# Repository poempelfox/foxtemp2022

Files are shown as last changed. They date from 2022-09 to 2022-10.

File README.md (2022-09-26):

# FoxTemp 2022

## Intro

This repository contains info about, firmware and a case for the
FoxTemp-Device version 2022.

This is very close to its predecessor, the "FoxTemp 2016",
the main changes are:
- uses a SHT41 (or SHT45) as a sensor instead of a SHT31/35. The
  SHT41 boasts with improved accuracy over its predecessor:
  a typical accuracy of &plusmn;1.8% RH (SHT31: &plusmn;2%)
  and &plusmn;0.2&deg;C (SHT31: &plusmn;0.3&deg;C) in the
  relevant ranges.
- uses a "Canique MK2" as the microprocessor base board, which
  in itself is a "Moteino V4" clone, so you could use that one as
  well. Unfortunately, there is no variant with a boost-converter
  onboard, like there was with the "JeeNode Micro". The boost
  converter needs to be an external "Canique Boost".

One thing did not change: The over-the-air protocol. It is not
possible to distinguish a foxtemp2022 from a foxtemp2016 at the
receiving end, both transmit exactly the same data format.

Note that you will also need a way to receive the wirelessly transmitted
data. I simply used a JeeLink v3c,
which is a simple USB transceiver for 868 MHz that is commonly used in
non-commercial home-automation systems. As such it is well supported by
FHEM, a popular non-commercial and cloud-free home-automation software.
A FHEM module for using it to feedg temperature data from foxtemp2016
or foxtemp2022 devices into FHEM can be found in the foxtemp2016 repository.

## Hardware

### Intro

This has been designed for low power usage, and when not transmitting the circuitry
uses only a fraction of a miliampere (around 0.05 mA at 2.8 volts input voltage,
this depends on the input voltage obviously). This should guarantee a long
battery life, but it's still unknown how long exactly this will be.
It also could be better if we weren't needlessly using a 16 MHz crystal
oscillator.
It will probably be slightly shorter than the one foxtemp2016 achieved,
but in the same order of magnitude.

### BOM

The hardware uses as many "ready made" parts as possible and just slaps them
together. The bill of materials therefore is short:

* [Canique MK2](https://www.canique.de/mk2), which is a "Moteino"
  clone and an ATtiny328P based microcontroller module with an
  RFM69HW 868 MHz wireless module. There are multiple versions of
  that, the one used here is the one without onboard voltage
  converter or flash.
* [Canique Boost](https://www.canique.de/boost), a very efficient
  step-up/boost converter. I can be powered by anything from 0.8
  to 3.3 volts and will generate the 3.3 volts the microcontroller
  and peripherals use from that.
* SHT41 temperature sensor, in the form of a
  [random SHT41 breakout board](https://www.soselectronic.com/products/various/sht-41-bob-373380).
  This is used because the SHT41 is very tiny, so soldering it directly
  without damaging it would not be an easy task, and because the breakout
  board serves perfectly as what would be called a "shield" in the Arduino
  world: It's plugged/stacked on top of the microcontroller board.
* Goobay 78467 battery tray. This is simply a battery holder for two
  AA / mignon batteries that has cables attached.
* 6pin angled or non-angled pin strip for the FTDI connector of the Canique MK2.
* 4pin (non-angled) pin strips male and female for connecting and mounting the
  SHT41 on top of the Canique MK2.
* 2pin (non-angled) pin strips male and female for connecting and mounting the
  Canique Boost on top of the Canique MK2

### Putting it together

Wanting to keep things as simple and compact as possible, I soldered the few
parts directly together as a stack. In the following description,
"top" means the side of the Canique MK2 / Moteino with the microcontroller,
the radio module is at the "bottom".

(to be continued)

## Case

A reference design for a laser-cut case that will fit the sensor construction
and the batteries (just like for foxtemp2016) is in the works. It is not
finished yet.

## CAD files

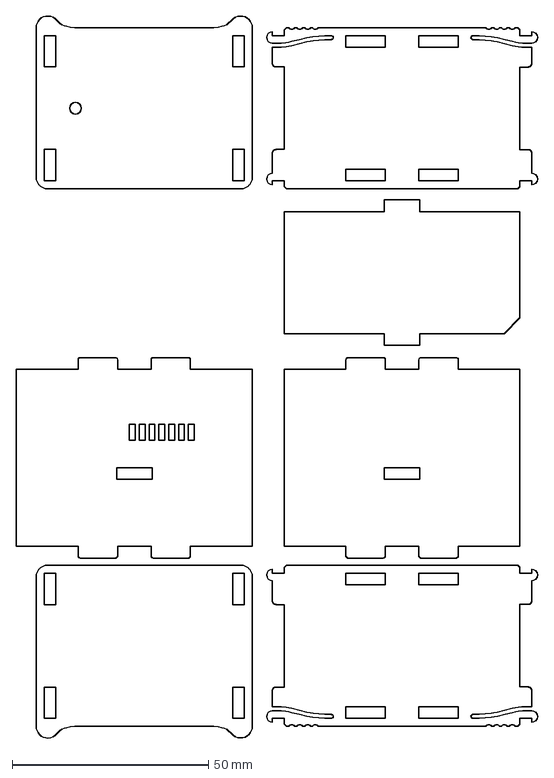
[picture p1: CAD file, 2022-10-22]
case/foxtempcaseacryl.dxf
132.6 x 183.7 mm

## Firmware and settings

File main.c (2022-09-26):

/* $Id: main.c $
 * main for JeeNode Weather Station, tieing all parts together.
 * (C) Michael "Fox" Meier 2016
 */

#include <avr/io.h>
#include <avr/interrupt.h>
#include <avr/wdt.h>
#include <avr/eeprom.h>
#include <avr/power.h>
#include <avr/sleep.h>
#include <stdio.h>
#include <string.h>
#include <util/delay.h>

#include "adc.h"
#include "eeprom.h"
#include "rfm69.h"
#include "sht4x.h"

/* We need to disable the watchdog very early, because it stays active
 * after a reset with a timeout of only 15 ms. */
void dwdtonreset(void) __attribute__((naked)) __attribute__((section(".init3")));
void dwdtonreset(void) {
  MCUSR = 0;
  wdt_disable();
}

/* The values last measured */
/* temperature. 0xffff on error, 14 useful bits. */
uint16_t temp = 0;
/* humidity. 0xffff on error, 14 useful bits */
uint16_t hum = 0;
/* Battery level. Range 0-255, 255 = our supply voltage = 3,3V */
uint8_t batvolt = 0;
/* How often did we send a packet? */
uint32_t pktssent = 0;

/* This is just a fallback value, in case we cannot read this from EEPROM
 * on Boot */
uint8_t sensorid = 3; // 0 - 255 / 0xff

/* The frame we're preparing to send. */
static uint8_t frametosend[10];

static uint8_t calculatecrc(uint8_t * data, uint8_t len)
{
  uint8_t i, j;
  uint8_t res = 0;
  for (j = 0; j < len; j++) {
    uint8_t val = data[j];
    for (i = 0; i < 8; i++) {
      uint8_t tmp = (uint8_t)((res ^ val) & 0x80);
      res <<= 1;
      if (0 != tmp) {
        res ^= 0x31;
      }
      val <<= 1;
    }
  }
  return res;
}

/* Fill the frame to send with out collected data and a CRC.
 * The protocol we use is that of a "CustomSensor" from the
 * FHEM LaCrosseItPlusReader sketch for the Jeelink.
 * So you'll just have to enable the support for CustomSensor in that sketch
 * and flash it onto a JeeNode and voila, you have your receiver.
 *
 * Byte  0: Startbyte (=0xCC)
 * Byte  1: Sensor-ID (0 - 255/0xff)
 * Byte  2: Number of data bytes that follow (6)
 * Byte  3: Sensortype (=0xf7 for FoxTemp)
 * Byte  4: temperature MSB (raw value from SHT31)
 * Byte  5: temperature LSB
 * Byte  6: humidity MSB (raw value from SHT31)
 * Byte  7: humidity LSB
 * Byte  8: Battery voltage
 * Byte  9: CRC
 */
void prepareframe(void)
{
  frametosend[ 0] = 0xCC;
  frametosend[ 1] = sensorid;
  frametosend[ 2] = 6; /* 6 bytes of data follow (CRC not counted) */
  frametosend[ 3] = 0xf7; /* Sensor type: FoxTemp */
  frametosend[ 4] = (temp >> 8) & 0xff;
  frametosend[ 5] = (temp >> 0) & 0xff;
  frametosend[ 6] = (hum >> 8) & 0xff;
  frametosend[ 7] = (hum >> 0) & 0xff;
  frametosend[ 8] = batvolt;
  frametosend[ 9] = calculatecrc(frametosend, 9);
}

void loadsettingsfromeeprom(void)
{
  uint8_t e1 = eeprom_read_byte(&ee_sensorid);
  uint8_t e2 = eeprom_read_byte(&ee_invsensorid);
  if ((e1 ^ 0xff) == e2) { /* OK, the 'checksum' matches. Use this as our ID */
    sensorid = e1;
  }
}

/* This is just to wake us up from sleep, it doesn't really do anything. */
ISR(WDT_vect)
{
  /* Nothing to do here. */
}

int main(void)
{
  /* Initialize stuff */
  /* Clock down from 16.0 to 0.25 MHz. */
  CLKPR = _BV(CLKPCE);
  CLKPR = _BV(CLKPS2) | _BV(CLKPS1);
  
  _delay_ms(1000); /* Wait. */

  rfm69_initport();
  adc_init();
  sht4x_init();
  loadsettingsfromeeprom();
  
  _delay_ms(1000); /* The RFM12 needs some time to start up */
  
  rfm69_initchip();
  rfm69_setsleep(1);
  
  /* Enable watchdog timer interrupt with a timeout of 8 seconds */
  WDTCSR = _BV(WDCE) | _BV(WDE);
  WDTCSR = _BV(WDE) | _BV(WDIE) | _BV(WDP0) | _BV(WDP3);

  /* Prepare sleep mode */
  set_sleep_mode(SLEEP_MODE_PWR_DOWN);
  sleep_enable();

  /* Disable unused chip parts and ports */
  /* We do not use any of the timers */
  PRR |= _BV(PRTIM0) | _BV(PRTIM1) | _BV(PRTIM2);
  /* we don't use hardware TWI */
  PRR |= _BV(PRTWI);
  /* Disable analog comparator */
  ACSR |= _BV(ACD);
  /* Disable unneeded digital input registers for all unused ADC pins
   * (they can cause significant power drain in some conditions).
   * Do not disable them for AIN0/1 aka PD6/7, they are in use! */
  DIDR0 |= _BV(ADC5D) | _BV(ADC4D) | _BV(ADC3D) | _BV(ADC2D) | _BV(ADC1D) | _BV(ADC0D);
  /* PD2 is the IRQ line from the RFM69. We don't use it. Make sure that pin
   * is tristated on our side (it won't float, the RFM69 pulls it) */
  PORTD &= (uint8_t)~_BV(PD2);
  DDRD &= (uint8_t)~_BV(PD2);

  /* there is a LED connected to PB1 */
  PORTB &= (uint8_t)~_BV(PB1);
  DDRB |= _BV(PB1);
  /* All set up, enable interrupts and go. */
  sei();

  sht4x_startmeas();

  uint16_t transmitinterval = 2; /* this is in multiples of the watchdog timer timeout (8S)! */
  uint8_t mlcnt = 0;
  uint8_t readerrcnt = 0;
  while (1) { /* Main loop, we should never exit it. */
#ifdef BLINKLED
    PORTB |= _BV(PB1);
#endif /* BLINKLED */
    mlcnt++;
    if (mlcnt > transmitinterval) {
      rfm69_setsleep(0);  /* This mainly turns on the oscillator again */
      adc_power(1);
      adc_start();
      /* Fetch values from PREVIOUS measurement */
      struct sht4xdata hd;
      sht4x_read(&hd);
      temp = 0xffff;
      hum = 0xffff;
      if (hd.valid) {
        readerrcnt = 0;
        temp = hd.temp;
        hum = hd.hum;
      } else {
        readerrcnt++;
        if (readerrcnt > 5) {
          /* We could not read the SHT31 5 times in a row?! */
          /* Then force reset through watchdog timer. */
          while (1) {
            sleep_cpu();
          }
        }
      }
      sht4x_startmeas();
      /* read voltage from ADC */
      uint16_t adcval = adc_read();
      adc_power(0);
      /* we have the battery pack directly connected without a
       * voltage divider, while foxtemp2016 did have a voltage
       * divider, returning 10/11 of the real voltage. However,
       * it was also operating at 3.0V, while we run at 3.3V.
       * The factor between that is 11/10, which means that by
       * pure accident our reported voltage values are exactly
       * compatible with foxtemp2016 without any conversion. */
      batvolt = adcval >> 2;
      prepareframe();
      rfm69_sendarray(frametosend, 10);
      pktssent++;
      /* Semirandom delay: the lowest bits from the ADC are mostly noise, so
       * we use that */
      transmitinterval = 3 + (adcval & 0x0001);
      rfm69_setsleep(1);
      mlcnt = 0;
    }
#ifdef BLINKLED
    PORTB &= (uint8_t)~_BV(PB1);
#endif /* BLINKLED */
    wdt_reset();
    /* Disable Brown-Out-Detector during sleep to save power.
     * Timed sequence, both lines setting it are needed even though
     * they might seem redundant, and they must not be executed
     * more than 4 cycle before going to sleep. */
    sleep_bod_disable();
    sleep_cpu(); /* Go to sleep until the watchdog timer wakes us */
    /* We should only reach this if we were just woken by the watchdog timer.
     * We need to re-enable the watchdog-interrupt-flag, else the next watchdog
     * -reset will not just trigger the interrupt, but be a full reset. */
    WDTCSR = _BV(WDCE) | _BV(WDE);
    WDTCSR = _BV(WDE) | _BV(WDIE) | _BV(WDP0) | _BV(WDP3);
  }
}

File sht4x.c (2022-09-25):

/* $Id: sht4x.c $
 * Functions for reading the SHT 41 (or other SHT4x variants)
 * temperature / humidity sensor
 *
 * Also includes functions for bitbanging I2C over two pins of the AVR,
 * which mostly come from the old NTP LED clock project.
 */

#include <avr/io.h>
#include <inttypes.h>
#include <util/delay.h>
#include "sht4x.h"

/* The Port used for the connection */
#define BBTWIPORT PORTD
#define BBTWIPIN PIND
#define BBTWIDDR DDRD

/* Which pins of the port */
#define PWRPIN PD4
#define SDAPIN PD5
#define SCLPIN PD6
#define GNDPIN PD7

#define I2C_READ  0x01
#define I2C_WRITE 0x00

/* The I2C address of the sensor. */
#define SHT4X_I2C_ADDR (0x44 << 1)

/* Commands for the sensor.  Only the ones we are likely
 * to use are listed here, look up the rest in the data sheet. */
/* Measurement with high precision */
#define SHT4X_CMD_MEASURE_HIGH 0xFD

/* FIXME */
#define DELAYVAL 14

void sht4x_init(void)
{
  /* We abuse two I/O ports to provide Power to the SHT4x */
  BBTWIPORT &= (uint8_t)~_BV(GNDPIN);
  BBTWIDDR |= _BV(GNDPIN);
  BBTWIPORT |= _BV(PWRPIN);
  BBTWIDDR |= _BV(PWRPIN);
  /* Initialize I2C bus: Enable pullups. */
  BBTWIPORT |= _BV(SCLPIN);
  BBTWIPORT |= _BV(SDAPIN);
  /* There is nothing to initialize at the SHT4x really,
   * its powerup-default-config should be fine for us. */
}

/* Send START, defined as high-to-low SDA with SCL high.
 * Expects SCL and SDA to be high already (pullups on)!
 * Returns with SDA and SCL actively pulled low. */
static void bbtwi_start(void) {
  /* Change to output mode. */
  BBTWIDDR |= _BV(SDAPIN);
  BBTWIDDR |= _BV(SCLPIN);
  /* change SDA to low */
  BBTWIPORT &= (uint8_t)~_BV(SDAPIN);
  _delay_loop_1(DELAYVAL);
  /* and SCL too */
  BBTWIPORT &= (uint8_t)~_BV(SCLPIN);
  _delay_loop_1(DELAYVAL);
}

/* Send STOP, defined as low-to-high SDA with SCL high.
 * Expects SCL and SDA to be low already!
 * Returns with SDA and SCL high. */
static void bbtwi_stop(void) {
  /* Set SCL */
  BBTWIPORT |= _BV(SCLPIN);
  _delay_loop_1(DELAYVAL);
  /* Set SDA */
  BBTWIPORT |= _BV(SDAPIN);
  _delay_loop_1(DELAYVAL);
  /* Probably safer to tristate the bus */
  BBTWIDDR &= (uint8_t)~_BV(SDAPIN);
  BBTWIDDR &= (uint8_t)~_BV(SCLPIN);
}

/* Transmits the byte in what.
 * Returns 1 if the byte was ACKed, 0 if not.
 * Expects SCL to be driven low and SDA to be driven whatever way already!
 * Returns with SCL and SDA driven low. */
static uint8_t bbtwi_transmit_byte(uint8_t what) {
  uint8_t i;
  for (i = 0; i < 8; i++) {
    /* First put data on the bus */
    if (what & 0x80) {
      BBTWIPORT |= _BV(SDAPIN);
    }
    _delay_loop_1(DELAYVAL);
    /* Then set SCL high */
    BBTWIPORT |= _BV(SCLPIN);
    _delay_loop_1(DELAYVAL);
    /* Take SCL back */
    BBTWIPORT &= (uint8_t)~_BV(SCLPIN);
    _delay_loop_1(DELAYVAL);
    /* And SDA too */
    BBTWIPORT &= (uint8_t)~_BV(SDAPIN);
    _delay_loop_1(DELAYVAL);
    what <<= 1;
  }
  /* OK that was the data, now we read back the ACK */
  /* We need to tristate SDA for that */
  BBTWIPORT |= _BV(SDAPIN);
  BBTWIDDR &= (uint8_t)~_BV(SDAPIN);
  /* Give the device some time */
  _delay_loop_1(DELAYVAL);
  /* Then set SCL high */
  BBTWIPORT |= _BV(SCLPIN);
  _delay_loop_1(DELAYVAL);
  i = BBTWIPIN & _BV(SDAPIN); /* Read ACK */
  /* Take SCL back */
  BBTWIPORT &= (uint8_t)~_BV(SCLPIN);
  _delay_loop_1(DELAYVAL);
  /* No more tristate, we pull SDA again */
  BBTWIPORT &= (uint8_t)~_BV(SDAPIN);
  BBTWIDDR |= _BV(SDAPIN);
  _delay_loop_1(DELAYVAL);
  return (i == 0);
}

/* Reads a byte from the bus and returns it.
 * expects to start with SCL actively driven low.
 */
static uint8_t bbtwi_read_byte(uint8_t sendack)
{
  uint8_t res = 0;
  uint8_t i;
  /* Make sure SDA is pulled up high but not actively driven */
  BBTWIPORT |= _BV(SDAPIN);
  BBTWIDDR &= (uint8_t)~_BV(SDAPIN);
  for (i = 0; i < 8; i++) {
    /* Raise the clock line */
    BBTWIPORT |= _BV(SCLPIN);
    /* Wait for the slave to pull the data line */
    _delay_loop_1(DELAYVAL);
    res <<= 1;
    if (BBTWIPIN & _BV(SDAPIN)) {
      res |= 0x01;
    }
    BBTWIPORT &= (uint8_t)~_BV(SCLPIN);
    _delay_loop_1(DELAYVAL);
  }
  if (sendack) {
    /* Alrighty then, we should send an ACK: drive low SDA. */
    BBTWIPORT &= (uint8_t)~_BV(SDAPIN);
  }
  BBTWIDDR |= _BV(SDAPIN);
  _delay_loop_1(DELAYVAL);
  BBTWIPORT |= _BV(SCLPIN);
  /* Wait for the slave to pull the data line */
  _delay_loop_1(DELAYVAL);
  BBTWIPORT &= (uint8_t)~_BV(SCLPIN);
  _delay_loop_1(DELAYVAL);
  BBTWIPORT |= _BV(SDAPIN);
  BBTWIDDR &= (uint8_t)~_BV(SDAPIN);
  _delay_loop_1(DELAYVAL);
  return res;
}

void sht4x_startmeas(void)
{
  bbtwi_start();
  bbtwi_transmit_byte(SHT4X_I2C_ADDR | I2C_WRITE);
  /* single shot, high repeatability, no 'clock stretch' */
  bbtwi_transmit_byte(SHT4X_CMD_MEASURE_HIGH);
  bbtwi_stop();
}

/* This function is based on Sensirons example code and datasheet */
uint8_t sht4x_crc(uint8_t b1, uint8_t b2)
{
  uint8_t crc = 0xff; /* Start value */
  uint8_t b;
  crc ^= b1;
  for (b = 0; b < 8; b++) {
    if (crc & 0x80) {
      crc = (crc << 1) ^ 0x131;
    } else {
      crc = crc << 1;
    }
  }
  crc ^= b2;
  for (b = 0; b < 8; b++) {
    if (crc & 0x80) {
      crc = (crc << 1) ^ 0x131;
    } else {
      crc = crc << 1;
    }
  }
  return crc;
}

void sht4x_read(struct sht4xdata * d)
{
  d->valid = 0;
  bbtwi_start();
  /* There is no "command", just addressing the device while indicating a */
  /* read. The device will reply with NAK if it has not finished yet. */
  if (!bbtwi_transmit_byte(SHT4X_I2C_ADDR | I2C_READ)) {
    bbtwi_stop();
    return;
  }
  uint8_t b1 = bbtwi_read_byte(1);  /* Temp MSB */
  uint8_t b2 = bbtwi_read_byte(1);  /* Temp LSB */
  uint8_t b3 = bbtwi_read_byte(1);  /* Temp CRC */
  uint8_t b4 = bbtwi_read_byte(1);  /* Humi MSB */
  uint8_t b5 = bbtwi_read_byte(1);  /* Humi LSB */
  uint8_t b6 = bbtwi_read_byte(0);  /* Humi CRC */
  if ((sht4x_crc(b1, b2) == b3) && (sht4x_crc(b4, b5) == b6)) {
    d->valid = 1;
  }
  d->temp = (b1 << 8) | b2;
  d->hum = (b4 << 8) | b5;
  bbtwi_stop();
}

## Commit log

2022-09-25 address a few powersaving-FIXMEs
    [main.c, rfm69.c]
2022-09-26 more power-saving, mostly by clocking the microcontroller even slower (0.25 MHz should be enough for anybody!)
2022-09-29 minimally change transmit power and explain our choice
2022-10-16 a case to be lasered out of acryl - based on https://github.com/diy-electronics/raspberrypi-b-plus-case
    [foxtempcaseacryl.dxf]
2022-10-17 add SVG version of case
    [foxtempcaseacryl.dxf]
2022-10-22 attempt 2 for the case - hopefully with 100% less fail.
    [foxtempcaseacryl.dxf]
